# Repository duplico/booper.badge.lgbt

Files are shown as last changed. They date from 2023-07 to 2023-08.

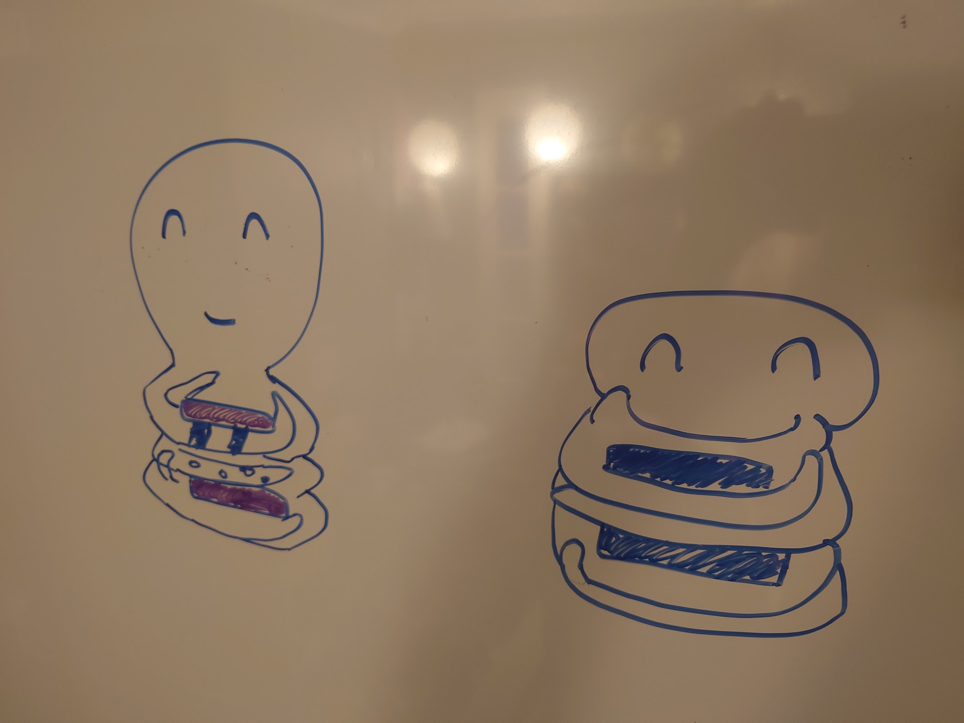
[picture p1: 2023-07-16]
doc/art/concept_sketch.JPG

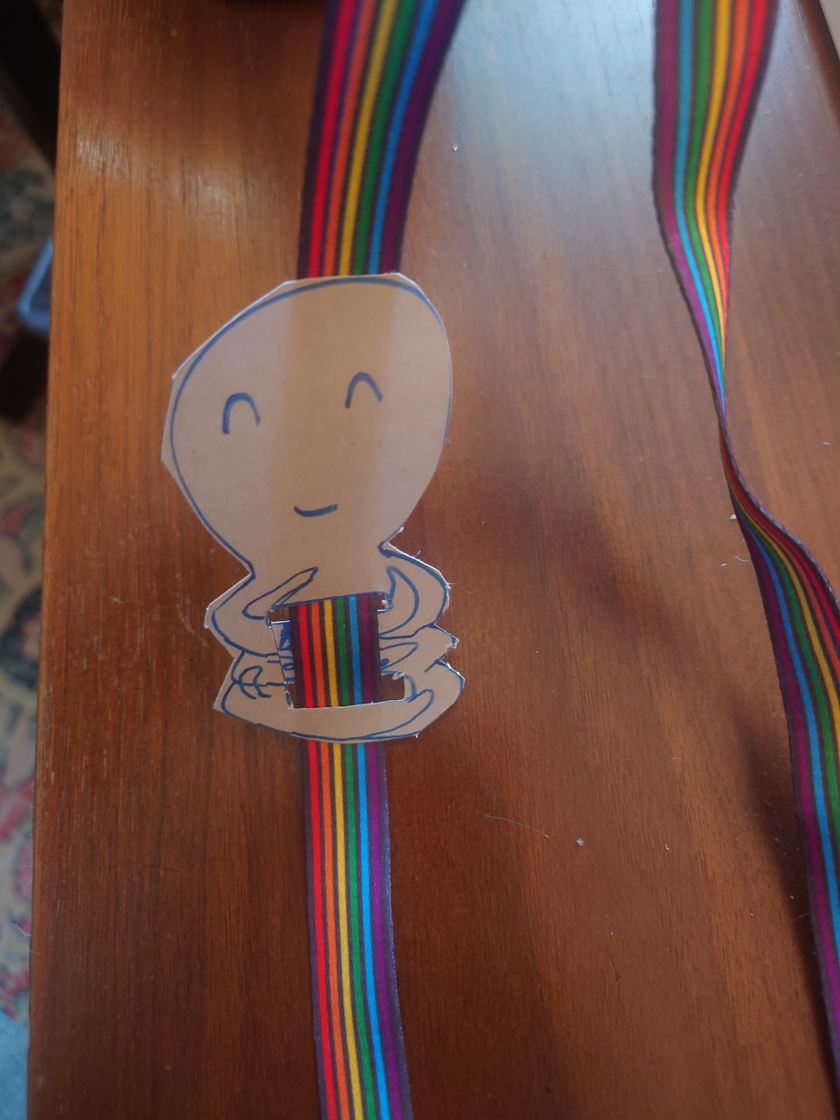
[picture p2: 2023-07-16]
doc/art/lanyard_mockup.JPG

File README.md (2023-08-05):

# booper.badge.lgbt

This is the 2023 `booper.badge.lgbt`! For more details, see https://booper.badge.lgbt.

## Support
Help us break even - https://ko-fi.com/badgelgbt/goal?g=11

## License
* Code is (c) 2023 George Louthan <duplico> except where otherwise marked. MIT license where possible.

## Credit
* duplico
* akio

## Acknowledgment
* Ink drawing - moeka2

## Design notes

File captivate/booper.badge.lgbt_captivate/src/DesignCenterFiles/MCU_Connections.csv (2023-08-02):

Sensor | Electrode | MCU Pin | Package Pin
B1 | RX00 | CAP0.1 | 17

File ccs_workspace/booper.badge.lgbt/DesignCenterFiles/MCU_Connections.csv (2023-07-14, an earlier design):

Sensor | Electrode | MCU Pin | Package Pin
B1 | RX00 | CAP0.0 | 16

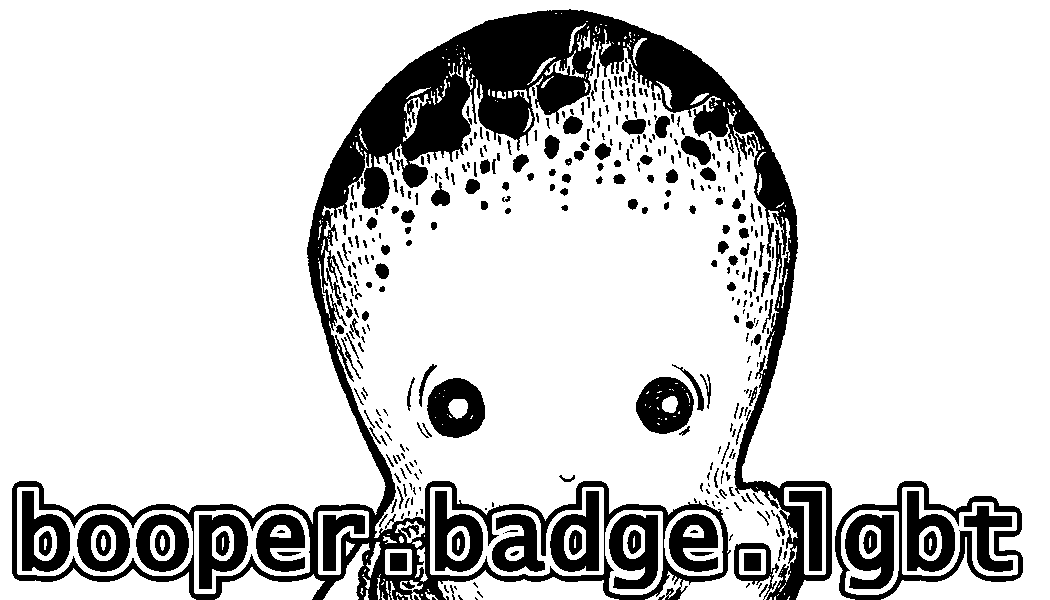
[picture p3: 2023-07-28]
stamp/stamp_filled.png

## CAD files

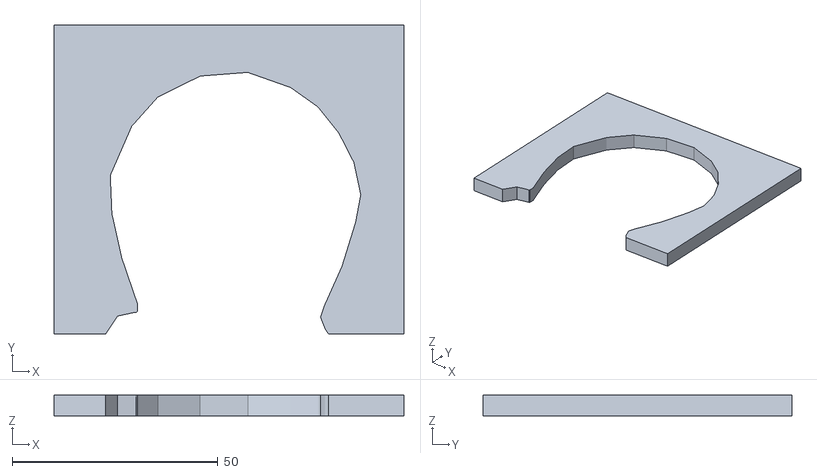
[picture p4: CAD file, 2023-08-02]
manufacture/holder.stl
85.0 x 75.0 x 5.00

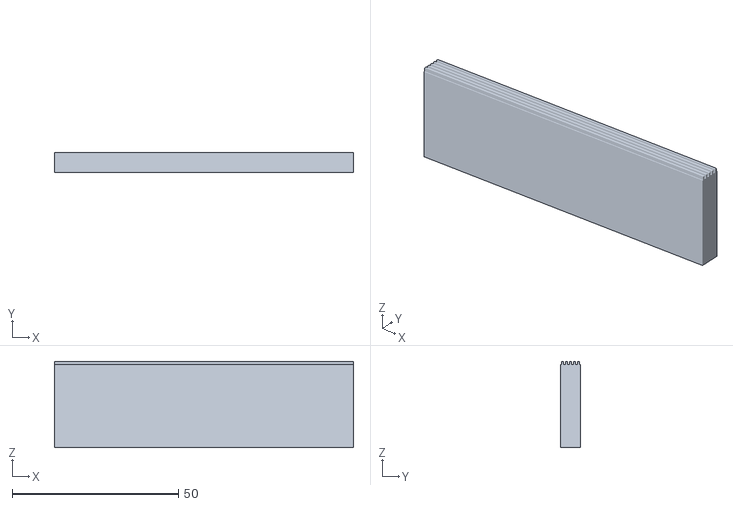
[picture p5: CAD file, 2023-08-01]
stamp/line_stamp_narrow.stl
90.0 x 6.00 x 26.0

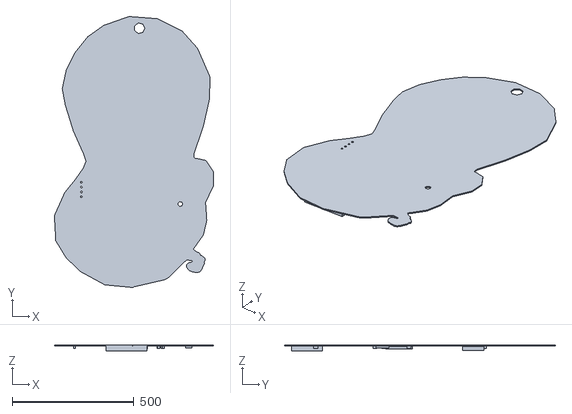
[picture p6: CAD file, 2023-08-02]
manufacture/PCB1_repaired_fixed.stl
654.5 x 1114.0 x 24.1

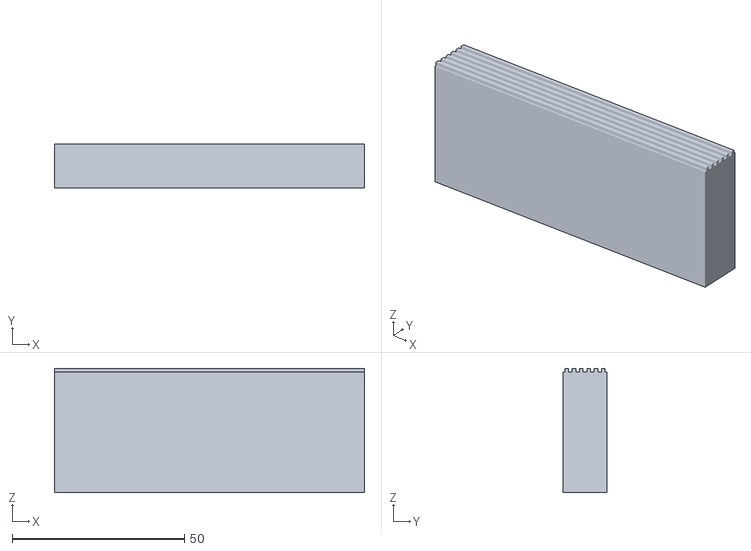
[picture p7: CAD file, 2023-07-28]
stamp/line_stamp.stl
90.0 x 12.7 x 36.0

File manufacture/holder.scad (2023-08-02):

OUTLINE_WIDTH = 85;
OUTLINE_HEIGHT = 120;
OUTLINE_THICKNESS = 5;

difference() {
    translate([-OUTLINE_WIDTH/2, -OUTLINE_HEIGHT/2, 0])
        cube([OUTLINE_WIDTH, OUTLINE_HEIGHT, OUTLINE_THICKNESS]);
    translate([0,0,-1]) rotate([0,180,0]) scale([0.1, 0.1, 5]) import("PCB1_repaired_fixed.stl",);
    translate([-OUTLINE_WIDTH/2,-75,0]) cube([OUTLINE_WIDTH, OUTLINE_HEIGHT/2, OUTLINE_THICKNESS]);
    translate([-5,36,0]) cube([10,10,10]);
}

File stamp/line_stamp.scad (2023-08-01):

LENGTH = 90;
WIDTH = 6;
LINES = 5;
BASE = 25;
STAMP_HEIGHT = 1;

cube([90, WIDTH, BASE]);

for(i = [0 : LINES-1]) {
    translate([0, 0.25 * WIDTH/LINES + i * (WIDTH/LINES), BASE])
        cube([90, 0.5 * WIDTH/LINES, STAMP_HEIGHT]);
}

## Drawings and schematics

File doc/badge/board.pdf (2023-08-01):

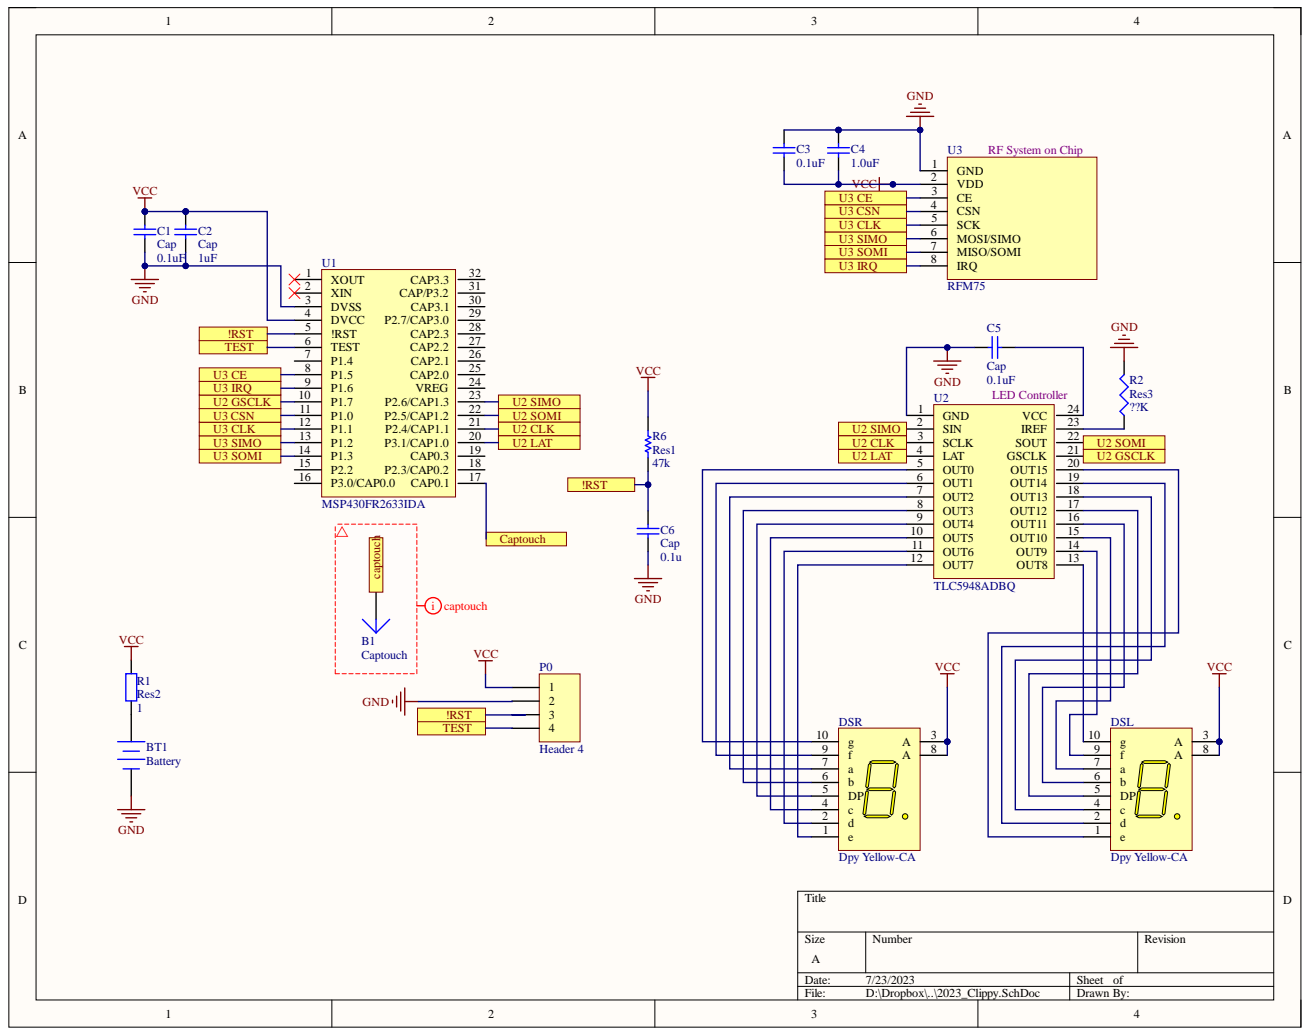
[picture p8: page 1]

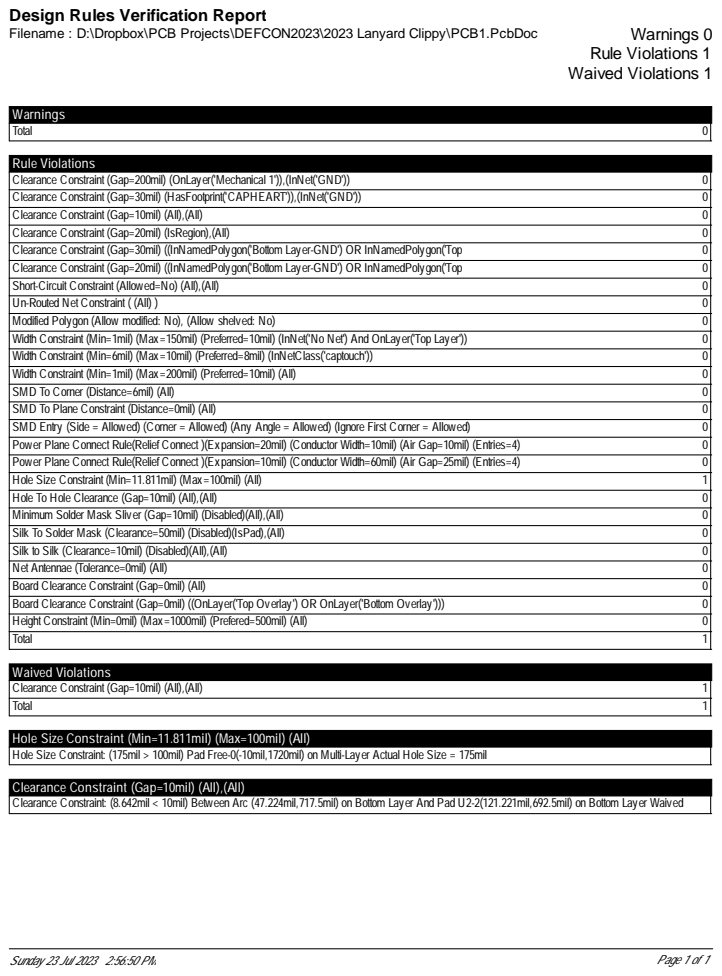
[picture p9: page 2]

Design Rules Verification Report

Hole Size Constraint (Min=11.811mil) (Max=100mil) (All)
Hole Size Constraint: (175mil > 100mil) Pad Free-0(-10mil,1720mil) on Multi-Layer Actual Hole Size = 175mil

Clearance Constraint (Gap=10mil) (All),(All)
Clearance Constraint: (8.642mil < 10mil) Between Arc (47.224mil,717.5mil) on Bottom Layer And Pad U2-2(121.221mil,692.5mil) on Bottom Layer Waived

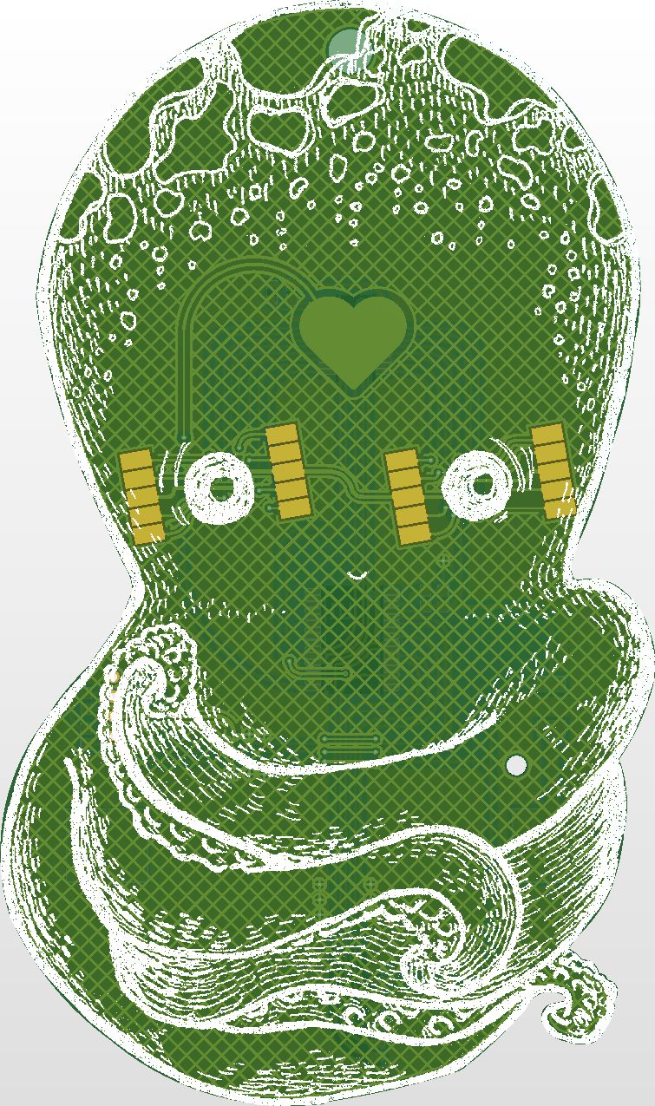
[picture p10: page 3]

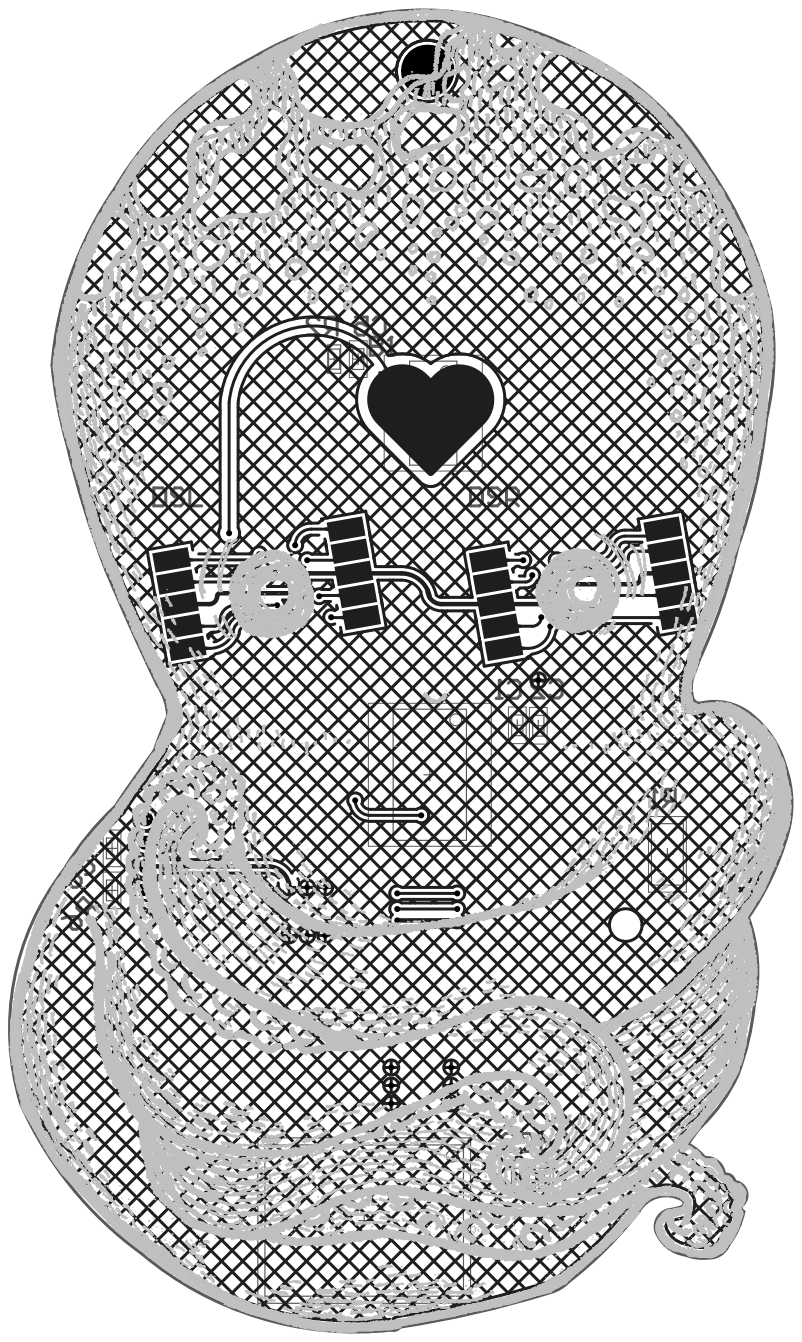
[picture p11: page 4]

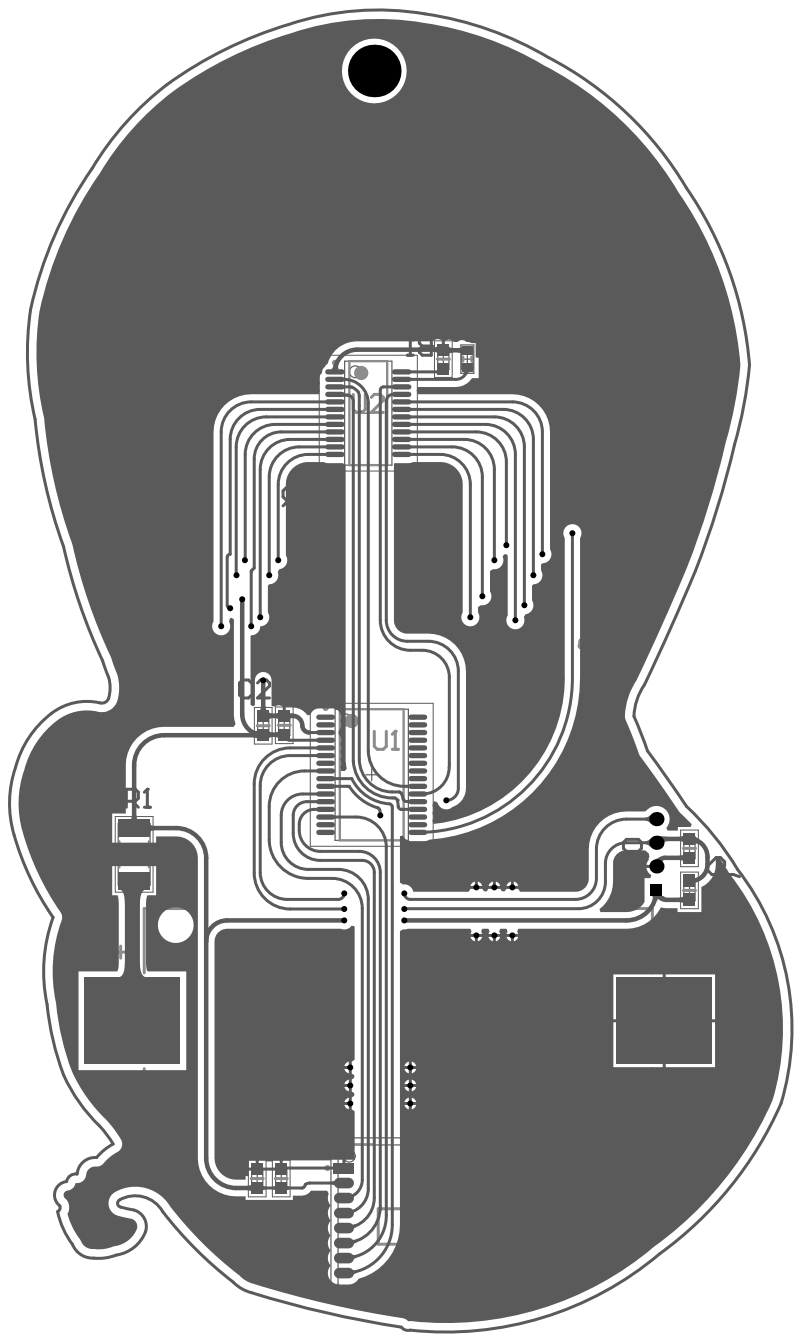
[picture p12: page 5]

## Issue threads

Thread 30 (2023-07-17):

Set correct eUSCI baudrate configuration for RFM75 driver

duplico, 2023-07-17:

duplico, 2023-08-01:
seems to work without any changes. sending it.

Closed 2023-08-01.

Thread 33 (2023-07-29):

Packaging and collateral

duplico, 2023-07-29:

duplico, 2023-08-01:
Keeping this open for follow ups

duplico, 2023-08-01:
Plan is Outside bag is heat-sealed tear-top paper bag.

* Pink bag for assembled badge (TULSA, after assembly)
* Sticker cut from sheet, loose in pink bag (TULSA)
* Little plastic bag for battery (VEGAS)
* Clips loose in paper bag (VEGAS)
* Paper bag heat-sealed (VEGAS)

duplico, 2023-08-03:
This all seems good.

Closed 2023-08-03.

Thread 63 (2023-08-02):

Captouch button only works when grounded to my PC

duplico, 2023-08-02:

duplico, 2023-08-02:
Resolved in #64

duplico, 2023-08-02:
(I configured it to use the wrong pin, lol)

Closed 2023-08-02.

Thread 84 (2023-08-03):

Build and bring a sufficiency

duplico, 2023-08-03:

duplico, 2023-08-03:
Jobs:

Kraft bags
* Stamp ~100 with black booper stamp
* Stamp ~15 with red booper stamp
* Stamp all with rainbow underline

Cut stickers
* Separate stickers into 1-up sheets

Assembly
* Apply solder paste to back with stencil
* Place components
* Bake

Inspection and completion
* Fix bridged joints

Program
* Apply code and ID

Verify
* Divert non-OK POST badges for repair; mark with arrow as appropriate
  * No lights at all: Arrow points to small chip on back
  * No lights on one eye, or eyes look messed up: Arrow to problem eye
  * ID error: Arrow on large chip on back; return to programming station for re-write
  * RF error: Arrow on green module on back; return for repair
* Click OK at POST and pull battery [STRETCH: when radio frequency is selected]

Repair
* Fix any POST errors

Pack
* Load flashed badges (no battery) into pink bag
* Load rainbow heart sticker (1) into pink bag
* Seal pink bag: done.

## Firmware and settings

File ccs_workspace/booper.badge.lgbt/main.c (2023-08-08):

/// booper.badge.lgbt 2023 low-level entry point.
/**
 ** The main source module is concerned with the basic setup of the MCU and
 ** onboard GPIO and peripherals. It also contains the main program loop of
 ** the entire badge code. Aside from initialization of peripherals and the
 ** other badge drivers, this module has a core purpose of calling events in
 ** (primarily) the badge.c module.
 **
 ** The basic split in responsibility between the badge.c and main.c modules
 ** is that main.c detects, prioritizes, and clears flags set from
 ** interrupts; it then calls the appropriate function in badge.c so that
 ** badge.c can behave in a more event-driven way, with the underlying MSP430
 ** hardware and registers abstracted away by main.c for the most part.
 **
 ** \file main.c
 ** \author George Louthan
 ** \date   2023
 ** \copyright (c) 2023 George Louthan @duplico. MIT License.
 */

// MSP430 headers
#include <msp430fr2633.h>
#include <driverlib.h>

// CapTIvate
#include "captivate.h"
#include "CAPT_App.h"

// System headers
#include <stdint.h>
#include <stdlib.h>

// Project headers
#include "badge.h"
#include "rtc.h"
#include "tlc5948a.h"
#include "radio.h"
#include "rfm75.h"
#include "leds.h"
#include "util.h"

/// Current button state (1 for pressed, 2 for long-pressed, 0 not pressed).
volatile uint8_t button_state;

/// Interrupt flag for the system clock tick.
volatile uint8_t f_time_loop;
/// Interrupt flag for the button being held for over 1 second.
volatile uint8_t f_button_press_long;
/// Interrupt flag that ticks every second.
volatile uint8_t f_second;
/// Signal to do a radio boop
uint8_t s_boop_radio = 0;

/// Perform the TI-recommended software trim of the DCO per TI demo code.
void dco_software_trim()
{
    unsigned int oldDcoTap = 0xffff;
    unsigned int newDcoTap = 0xffff;
    unsigned int newDcoDelta = 0xffff;
    unsigned int bestDcoDelta = 0xffff;
    unsigned int csCtl0Copy = 0;
    unsigned int csCtl1Copy = 0;
    unsigned int csCtl0Read = 0;
    unsigned int csCtl1Read = 0;
    unsigned int dcoFreqTrim = 3;
    unsigned char endLoop = 0;

    do
    {
        CSCTL0 = 0x100;                         // DCO Tap = 256
        do
        {
            CSCTL7 &= ~DCOFFG;                  // Clear DCO fault flag
        }while (CSCTL7 & DCOFFG);               // Test DCO fault flag

        __delay_cycles((unsigned int)3000 * MCLK_FREQ_MHZ);// Wait FLL lock status (FLLUNLOCK) to be stable
                                                           // Suggest to wait 24 cycles of divided FLL reference clock
        while((CSCTL7 & (FLLUNLOCK0 | FLLUNLOCK1)) && ((CSCTL7 & DCOFFG) == 0));

        csCtl0Read = CSCTL0;                   // Read CSCTL0
        csCtl1Read = CSCTL1;                   // Read CSCTL1

        oldDcoTap = newDcoTap;                 // Record DCOTAP value of last time
        newDcoTap = csCtl0Read & 0x01ff;       // Get DCOTAP value of this time
        dcoFreqTrim = (csCtl1Read & 0x0070)>>4;// Get DCOFTRIM value

        if(newDcoTap < 256)                    // DCOTAP < 256
        {
            newDcoDelta = 256 - newDcoTap;     // Delta value between DCPTAP and 256
            if((oldDcoTap != 0xffff) && (oldDcoTap >= 256)) // DCOTAP cross 256
                endLoop = 1;                   // Stop while loop
            else
            {
                dcoFreqTrim--;
                CSCTL1 = (csCtl1Read & (~(DCOFTRIM0+DCOFTRIM1+DCOFTRIM2))) | (dcoFreqTrim<<4);
            }
        }
        else                                   // DCOTAP >= 256
        {
            newDcoDelta = newDcoTap - 256;     // Delta value between DCPTAP and 256
            if(oldDcoTap < 256)                // DCOTAP cross 256
                endLoop = 1;                   // Stop while loop
            else
            {
                dcoFreqTrim++;
                CSCTL1 = (csCtl1Read & (~(DCOFTRIM0+DCOFTRIM1+DCOFTRIM2))) | (dcoFreqTrim<<4);
            }
        }

        if(newDcoDelta < bestDcoDelta)         // Record DCOTAP closest to 256
        {
            csCtl0Copy = csCtl0Read;
            csCtl1Copy = csCtl1Read;
            bestDcoDelta = newDcoDelta;
        }

    }while(endLoop == 0);                      // Poll until endLoop == 1

    CSCTL0 = csCtl0Copy;                       // Reload locked DCOTAP
    CSCTL1 = csCtl1Copy;                       // Reload locked DCOFTRIM
    while(CSCTL7 & (FLLUNLOCK0 | FLLUNLOCK1)); // Poll until FLL is locked
}

/// Prepare to write to FRAM by disabling interrupts and unlocking write access to INFOA.
volatile void fram_unlock() {
    __bic_SR_register(GIE);
    SYSCFG0 = FRWPPW | PFWP;
}

/// Finish writing to FRAM by locking write access to INFOA and enabling interrupts.
volatile void fram_lock() {
    SYSCFG0 = FRWPPW | DFWP | PFWP;
    __bis_SR_register(GIE);
}

/// Initialize clock signals and the three system clocks.
/**
 ** We'll take the DCO to 8 MHz, and divide it by 1 for MCLK = 8MHz.
 ** Then we'll divide MCLK by 1 to get 8 MHz SMCLK.
 **
 ** Our available clock sources are:
 **  VLO:     10kHz very low power low-freq
 **  REFO:    32.768kHz (typ) reference oscillator
 **  DCO:     Digitally controlled oscillator (1MHz default)
 **           Specifically, 1048576 Hz typical.
 **
 ** At startup, our clocks are as follows:
 **  MCLK:  Sourced by the DCO
 **         (Available: DCO, REFO, VLO)
 **  SMCLK: Sourced from MCLK, with no divider
 **         (Available dividers: {1,2,4,8})
 **  ACLK: Sourced from REFO
 **         (the only available internal source)
 **
 ** So the only change we need to make is to the DCO and MCLK.
 **
 */
void init_clocks() {

    __bis_SR_register(SCG0); // disable FLL
    CSCTL3 |= SELREF__REFOCLK; // Set REFO as FLL reference source
    CSCTL1 = DCOFTRIMEN | DCOFTRIM0 | DCOFTRIM1 | DCORSEL_3; // DCOFTRIM=3, DCO Range = 8MHz
    CSCTL2 = FLLD_0 + 243; // DCODIV = 8MHz
    __delay_cycles(3); // Documentation says to wait at least 3 cycles
    __bic_SR_register(SCG0); // enable FLL
    dco_software_trim(); // Software Trim to get the best DCOFTRIM value

    CSCTL4 = SELMS__DCOCLKDIV | SELA__REFOCLK; // set default REFO(~32768Hz) as ACLK source, ACLK = 32768Hz

    // default DCODIV as MCLK and SMCLK source, SMCLKOFF=0; no need to modify CSCTL5.
}

/// Apply the initial configuration of the GPIO and peripheral pins.
/**
 **
 */
void init_io() {
    // Per datasheet S4.6, p20, unused pins should be switched to outputs.

    // P1.0     GPIO CSN    (SEL 00; DIR 1) Initially HIGH
    // P1.1     UCB0CLK     (SEL 01; DIR 1)
    // P1.2     UCB0SIMO    (SEL 01; DIR 1)
    // P1.3     UCB0SOMI    (SEL 01; DIR 0)
    // P1.4     Unused      (SEL 00; DIR 1)
    // P1.5     GPIO CE     (SEL 00; DIR 1) Initially LOW
    // P1.6     GPIO IRQ    (SEL 00; DIR 0)
    // P1.7     SMCLK out   (SEL 10; DIR 1)

    // P2.0     Unused      (SEL 00; DIR 1)
    // P2.1     Unused      (SEL 00; DIR 1)
    // P2.2     Unused      (SEL 00; DIR 1)
    // P2.3     Unused      (SEL 00; DIR 1)
    // P2.4     UCA1CLK     (SEL 01; DIR 1)
    // P2.5     UCA1SOMI    (SEL 01; DIR 0)
    // P2.6     UCA1SIMO    (SEL 01; DIR 1)
    // P2.7     Unused      (SEL 00; DIR 1)

    // P3.0 is DONTCARE for CAP0.0
    // P3.1     TLC LAT     (SEL 00; DIR 1) Initially LOW
    // P3.2     Unused      (SEL 00; DIR 1)

    // P1
    P1DIR =     0b10110111;
    P1SEL0 =    0b00001110; // LSB
    P1SEL1 =    0b10000000; // MSB
    P1REN =     0b00000000;
    P1OUT =     0b00000001;

    // P2
    P2DIR =     0b11011111;
    P2SEL0 =    0b01110000; // LSB
    P2SEL1 =    0b00000000; // MSB
    P2REN =     0b00000000;
    P2OUT =     0b00000000;

    // P3
    P3DIR = 0xFF;
    P3SEL0 = 0x00;
    P3SEL1 = 0x00;
    P3OUT = 0x00;

    // Unlock the pins from high-impedance mode:
    // (AKA the MSP430FR magic make-it-work command)
    PM5CTL0 &= ~LOCKLPM5;
}

/// Callback from CapTIvate for a change in the button state.
void button_cb(tSensor *pSensor) {

    if((pSensor->bSensorTouch == true) && (pSensor->bSensorPrevTouch == false))
    {
        long_presses = 0;
        // Button press
         button_state = 1;
         rtc_button_csecs = 0;
    }

    if((pSensor->bSensorTouch == false) && (pSensor->bSensorPrevTouch == true))
    {
        // Button release
        if (long_presses == 9) {
            long_presses = 0;
            radio_start_calibration();
        } else if (button_state == 1) {
             // Only fire if it's not being long-pressed.
             badge_button_press_short();
         }
         button_state = 0;
    }
}

void post_display() {
    if (!rfm75_post()) {
        // Radio appears broken.
        leds_error_code(BADGE_POST_ERR_NORF);
    } else if (badge_conf.badge_id == BADGE_ID_UNASSIGNED) {
        leds_error_code(BADGE_POST_ERR_NOID);
    } else if (!radio_frequency_done) {
        leds_error_code(BADGE_POST_ERR_FREQ);
    } else {
        leds_error_code(BADGE_POST_ERR_NONE);
    }
}

/// Make snafucated
int main(void)
{
	WDTCTL = WDTPW | WDTHOLD;	// stop watchdog timer
	
	// Board basics initialization
	init_clocks();
	init_io();

	badge_init();

	__bis_SR_register(GIE);

    // Mid-level drivers initialization
    leds_init();

    // If we have something to show, go ahead and count our badges.
	if (badge_conf.bootstrapped && badge_conf.badges_seen_count > 1) {
	    for (uint8_t i=0; i<=(badge_conf.badges_seen_count < 100 ? badge_conf.badges_seen_count : 100); i++) {
	        leds_show_number(i, 0);
	        delay_millis(80);
	    }
	    delay_millis(6000);
	}

	// Application-level drivers initialization
    rtc_init();
	radio_init(badge_conf.badge_id);

	// CapTIvate initialization and startup
    MAP_CAPT_initUI(&g_uiApp);
    MAP_CAPT_calibrateUI(&g_uiApp);
    MAP_CAPT_registerCallback(&B1, &button_cb);

    MAP_CAPT_stopTimer();
    MAP_CAPT_clearTimer();
    MAP_CAPT_selectTimerSource(CAPT_TIMER_SRC_ACLK);
    MAP_CAPT_selectTimerSourceDivider(CAPT_TIMER_CLKDIV__1);
    MAP_CAPT_writeTimerCompRegister(CAPT_MS_TO_CYCLES(g_uiApp.ui16ActiveModeScanPeriod));
    MAP_CAPT_startTimer();
    MAP_CAPT_enableISR(CAPT_TIMER_INTERRUPT);

	// Application functionality initialization

    // Set up WDT, and we're off to see the wizard.
    WDTCTL = WDTPW | WDTSSEL__ACLK | WDTIS__32K | WDTCNTCL; // 1 second WDT

    uint8_t my_beacon_tick = badge_conf.badge_id % 8;
    uint8_t s_beacon = 0;
    uint8_t next_blink = 1;

    uint8_t bootstrap_error = BADGE_POST_ERR_NONE;
    if (badge_conf.badge_id == BADGE_ID_UNASSIGNED)
        bootstrap_error = BADGE_ID_UNASSIGNED;
    if (!rfm75_post())
        bootstrap_error = BADGE_POST_ERR_NORF;

    if (!badge_conf.bootstrapped) {
        // Show the POST message
        post_display();
        badge_block_radio_game = 1;
    }

	while (1) {
	    // The 100 Hz loop
	    if (f_time_loop) {
            f_time_loop = 0;

	        // pat pat pat
	        WDTCTL = WDTPW | WDTSSEL__ACLK | WDTIS__32K | WDTCNTCL; // 1 second WDT

	        if (badge_conf.bootstrapped)
	            leds_timestep();
	    }

	    if (f_button_press_long) {
            f_button_press_long = 0;

	        badge_button_press_long();
	    }

	    if (f_rfm75_interrupt) {
	        rfm75_deferred_interrupt();
	    }

	    // Check whether CapTIvate needs to be serviced.
	    if (g_bConvTimerFlag) {
            g_bConvTimerFlag = 0;

	        CAPT_updateUI(&g_uiApp);
	    }

        // The 1 Hz loop - lower priority
        if (f_second) {
            f_second = 0;

            if (!radio_frequency_done) {
                leds_post_step();
                // Still calibrating our radio frequency.
                static uint8_t radio_calibration_freq_seconds_left = BADGE_RADIO_CALIBRATION_SECS_PER_FREQ;
                if (!radio_calibration_freq_seconds_left) {
                    // Done with a frequency.
                    fram_unlock();
                    radio_frequency++;
                    fram_lock();

                    if (radio_frequency == FREQ_MIN+FREQ_NUM) {
                        // Just finished the last frequency. Decide which is the best.
                        uint16_t cnt = 0;
                        for (uint8_t i=FREQ_MIN; i<FREQ_MIN+FREQ_NUM; i++) {
                            if (rx_cnt[i-FREQ_MIN] > cnt) {
                                // New best frequency
                                cnt = rx_cnt[i-FREQ_MIN];
                                fram_unlock();
                                radio_frequency = i;
                                fram_lock();
                            }
                        }
                        if (cnt || badge_conf.bootstrapped) { // If it's already bootstrapped we only want to try once.
                            // If we got anything at all on our best frequency, conclude our search.
                            fram_unlock();
                            radio_frequency_done = 1;
                            fram_lock();
                            rfm75_write_reg(0x05, radio_frequency);

                            // Display our selected frequency.
                            leds_show_number(radio_frequency, 400);
                            if (bootstrap_error) {
                                // frequency calibration completed; if there was a POST error, show it.
                                post_display();
                            }
                        } else {
                            // Nothing received - start over.
                            fram_unlock();
                            radio_frequency = FREQ_MIN;
                            fram_lock();
                        }
                    }
                    rfm75_write_reg(0x05, radio_frequency);
                    radio_calibration_freq_seconds_left = badge_conf.bootstrapped ? BADGE_RADIO_CALIBRATION_SECS_PER_FREQ : BADGE_RADIO_CALIBRATION_SECS_PER_FREQ_INITIAL;
                } else {
                    // Decrement seconds left on the current frequency.
                    radio_calibration_freq_seconds_left--;
                }
            }

            if (badge_block_radio_game) {
                continue;
            }

            if (rtc_seconds % 8 == my_beacon_tick) {
                // Time to send a radio beacon
                s_beacon = 1;
            }

            if (!next_blink) {
                    leds_blink_or_bling();
                next_blink = rand() % BADGE_SECS_PER_BLINK_AVG;
            } else {
                next_blink--;
            }

            if (badge_boop_radio_cooldown) {
                badge_boop_radio_cooldown--;
            }
        }

	    if (s_beacon) {
	        // It's been 8 seconds, time to process the queerdar.
	        if (rfm75_tx_avail()) {
	            s_beacon = 0;
	            if (!badge_block_radio_game)
	                radio_interval();
	        }
	    }

	    if (s_boop_radio && rfm75_tx_avail()) {
	        s_boop_radio = 0;
            if (!badge_block_radio_game)
                radio_boop(badge_conf.badge_id, BADGE_BOOP_RADIO_HOPS);
	    }

	    // Enter sleep mode if we have no unserviced flags.
	    if (
	            !f_time_loop &&
	            !f_second &&
	            !f_button_press_long &&
	            !f_rfm75_interrupt &&
	            !g_bConvTimerFlag
	    ) {
	        __bis_SR_register(LPM0_bits);
	    }
	}
}

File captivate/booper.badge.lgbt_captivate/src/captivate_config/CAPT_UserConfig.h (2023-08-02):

/* --COPYRIGHT--,BSD
 * Copyright (c) 2017, Texas Instruments Incorporated
 * All rights reserved.
 *
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
 * *  Redistributions of source code must retain the above copyright
 *    notice, this list of conditions and the following disclaimer.
 *
 * *  Redistributions in binary form must reproduce the above copyright
 *    notice, this list of conditions and the following disclaimer in the
 *    documentation and/or other materials provided with the distribution.
 *
 * *  Neither the name of Texas Instruments Incorporated nor the names of
 *    its contributors may be used to endorse or promote products derived
 *    from this software without specific prior written permission.
 *
 * THIS SOFTWARE IS PROVIDED BY THE COPYRIGHT HOLDERS AND CONTRIBUTORS "AS IS"
 * AND ANY EXPRESS OR IMPLIED WARRANTIES, INCLUDING, BUT NOT LIMITED TO,
 * THE IMPLIED WARRANTIES OF MERCHANTABILITY AND FITNESS FOR A PARTICULAR
 * PURPOSE ARE DISCLAIMED. IN NO EVENT SHALL THE COPYRIGHT OWNER OR
 * CONTRIBUTORS BE LIABLE FOR ANY DIRECT, INDIRECT, INCIDENTAL, SPECIAL,
 * EXEMPLARY, OR CONSEQUENTIAL DAMAGES (INCLUDING, BUT NOT LIMITED TO,
 * PROCUREMENT OF SUBSTITUTE GOODS OR SERVICES; LOSS OF USE, DATA, OR PROFITS;
 * OR BUSINESS INTERRUPTION) HOWEVER CAUSED AND ON ANY THEORY OF LIABILITY,
 * WHETHER IN CONTRACT, STRICT LIABILITY, OR TORT (INCLUDING NEGLIGENCE OR
 * OTHERWISE) ARISING IN ANY WAY OUT OF THE USE OF THIS SOFTWARE,
 * EVEN IF ADVISED OF THE POSSIBILITY OF SUCH DAMAGE.
 * --/COPYRIGHT--*/


// Generated by Captivate Design Center v1_83_00_08 on Wed Aug 02 13:32:03 CDT 2023


//*****************************************************************************
// CAPT_UserConfig.h
//
//! The Captivate touch library UserConfig component defines the architecture
//! of the capacitive touch panel that is being implemented.
//
//! \version 1.83.00.05
//! Released on May 15, 2020
//
//*****************************************************************************

//*****************************************************************************
//
// NOTE: This is an automatically generated source code file!  The Captivate
// Design Center generates the User Configuration file automatically based
// upon the sensor layout that was created.
//
// Changes to this file will be OVERWRITTEN if a you select
// "Update Existing Project" under "Generate Source Code" in the Design Center.
//
// To avoid interference with the code generation process, keep ALL application
// code external to this file.
//
//*****************************************************************************

#ifndef CAPT_USERCONFIG_H_
#define CAPT_USERCONFIG_H_

//
// CapTIvate User Configuration Template Version
//
#ifndef __CAPTIVATE_CONFIG_VERSION__
#define __CAPTIVATE_CONFIG_VERSION__ 18300
#endif

//
// Include the CapTIvate Software Library
//
#include "captivate.h"

//
// Compile-Time System Configuration Definitions
//
#define CAPT_SENSOR_COUNT                     (1)
#define CAPT_INTERFACE  (__CAPT_NO_INTERFACE__)
#define CAPT_WAKEONPROX_ENABLE  (false)
#define CAPT_WAKEONPROX_SENSOR  (none)
#define CAPT_TRACKPAD_ENABLE  (false)
#define CAPT_LOW_POWER_MODE (LPM0_bits)

//
// Compile-Time Noise Immunity Configuration Definitions
//
#define CAPT_CONDUCTED_NOISE_IMMUNITY_ENABLE  (true)
#define CAPT_SELF_MODE_CONVERSION_STYLE  (eMultiFrequency)
#define CAPT_PROJ_MODE_CONVERSION_STYLE  (eMultiFrequencyWithOutlierRemoval)
#define CAPT_SELF_MODE_OVERSAMPLING_STYLE  (eNoOversampling)
#define CAPT_PROJ_MODE_OVERSAMPLING_STYLE  (eNoOversampling)
#define CAPT_NOISE_THRESHOLD  (50)
#define CAPT_CALIBRATION_NOISE_LIMIT  (50)
#define CAPT_DYNAMIC_THRESHOLD_ADJUSTMENT  (true)

//
// Captivate Frequency Count Definitions
// If conducted noise is enabled, multiple
// frequency scanning is enabled.  These definitions
// ensure that RAM space is set aside to store
// frequency specific information.
//
#if CAPT_CONDUCTED_NOISE_IMMUNITY_ENABLE
#define CAPT_SELF_FREQ_CNT        (4)
#define CAPT_MUTUAL_FREQ_CNT      (4)
#else
#define CAPT_SELF_FREQ_CNT        (1)
#define CAPT_MUTUAL_FREQ_CNT      (1)
#endif

//*****************************************************************************
//
//! \def CAPT_MS_TO_CYCLES is a macro to convert a period value in 
//! milliseconds to an approximate cycle count based on a 
//! 32.768 kHz clock frequency.
//
//*****************************************************************************
#define CAPT_MS_TO_CYCLES(ms)                                         (ms * 32)

//*****************************************************************************
//
//! \def CAPT_MS_TO_CYCLES_VLO is a macro to convert a period value in
//! milliseconds to an approximate cycle count based on a
//! 10 kHz clock frequency.  The VLO oscillator is approximately 10 kHz.
//
//*****************************************************************************
#define CAPT_MS_TO_CYCLES_VLO(ms)                                     (ms * 10)
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

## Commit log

2023-07-14 Add changes for CapTIvate to application.
    [MCU_Connections.csv]
2023-07-16 Add button press code.
2023-07-16 Add TLC5948A driver from QC2022 badge, using wrong eUSCI for this project.
    [tlc5948a.c]
2023-07-16 Remove the timer initialization
2023-07-16 Add unfinished GPIO config, pending schematic finalization.
2023-07-16 Add low-level RFM75 driver.
2023-07-17 Update block diagram per latest schematic.
2023-07-17 Initialize IO per this board design.
2023-07-17 Add a TODO to fix radio module SPI baudrate.
2023-07-28 Add packaging stamp files.
    [line_stamp.scad, line_stamp.stl]
2023-07-29 Rename project.
    [MCU_Connections.csv]
2023-08-01 Restore some driver code
2023-08-01 Add narrower stamp source
    [line_stamp.scad, line_stamp_narrow.stl]
2023-08-01 Add mid-level LED driver code.
2023-08-02 Update CapTIvate config
    [MCU_Connections.csv]
2023-08-02 Clear a current blink when beginning an animation
2023-08-02 Add paste jig files.
    [PCB1_repaired_fixed.stl, holder.scad, holder.stl]
2023-08-04 Do an LED POST while calibrating frequency
2023-08-04 Prevent radio game activity if not bootstrapped at boot.
    [badge.h, main.c]
2023-08-04 Long press for 9 blinks to calibrate radio frequency
2023-08-04 Fix the weird circular typedef issue.
    [main.c, rfm75.h]
2023-08-05 Add new stamp gcode for Cadet printer
2023-08-08 Increase speed of initial calibration
